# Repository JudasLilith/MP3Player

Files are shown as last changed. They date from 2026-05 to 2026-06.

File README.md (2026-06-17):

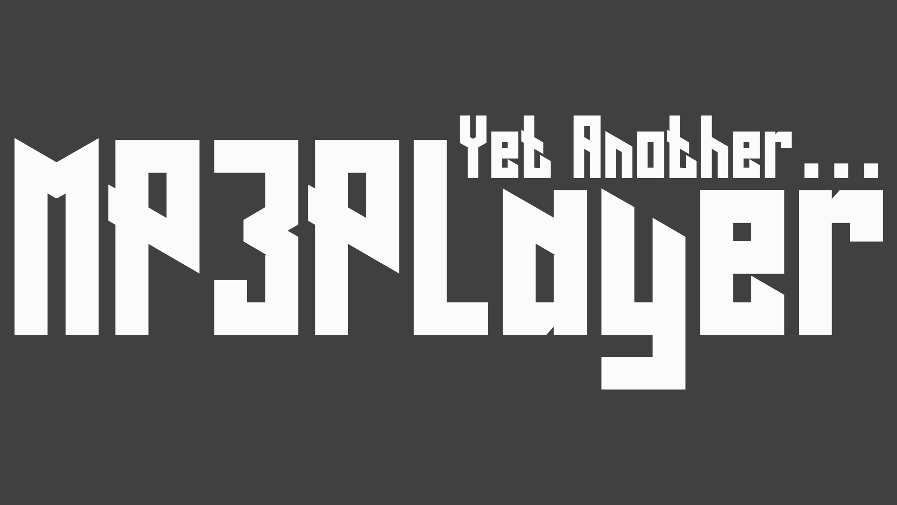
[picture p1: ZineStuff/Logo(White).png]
title


__Yet another MP3 Player, based on the DFRobot player. made for Hack Club Fallout(woohoo!!)__

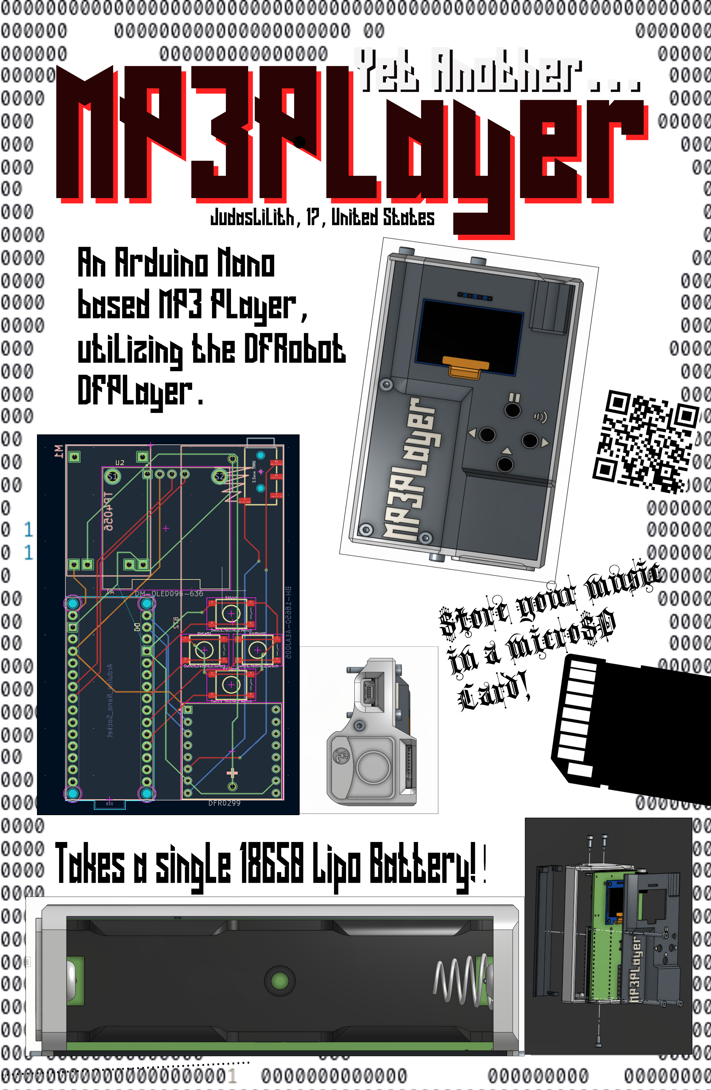
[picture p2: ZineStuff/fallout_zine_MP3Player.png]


## Introduction

Last year, the state of texas passed a law banning phones in all public schools. This came as a devastating effect for people who used their phones for academic purposes and people who listened to music in their free time. This situation made me find ways to listen to my playlist, and prompted me to make this project.

This project is highly influenced from other similar projects, such as:

* <https://github.com/Neutrino-1/Arduino-Soundpod> (this one even has a [instructables page](https://www.instructables.com/Arduino-Retro-Style-MP3-Player/))
* <https://fallout.hackclub.com/projects/755>
* <https://fallout.hackclub.com/projects/2789>

The MP3Player works by using the DFrobot DFPlayer, where all the songs are stored inside a microSD card. Each of the files have a specific 4-digit number, and those are used to find or traverse through the music.

## Gallery

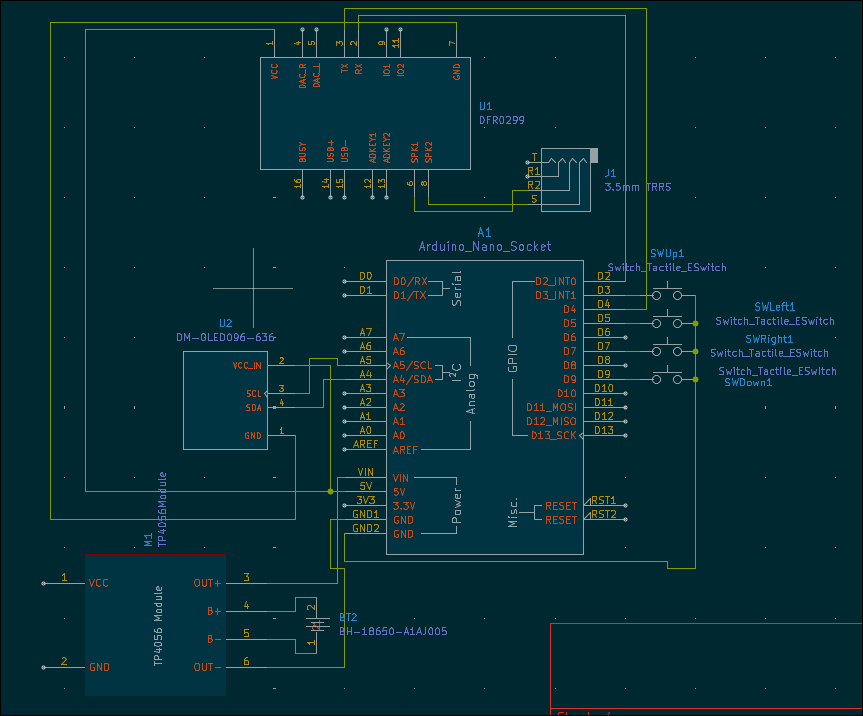
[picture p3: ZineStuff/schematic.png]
schematic

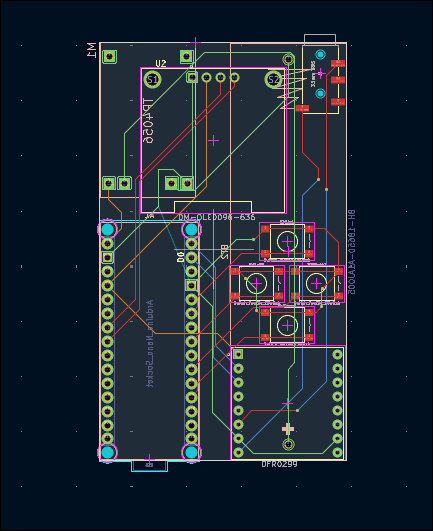
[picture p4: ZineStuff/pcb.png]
pcb

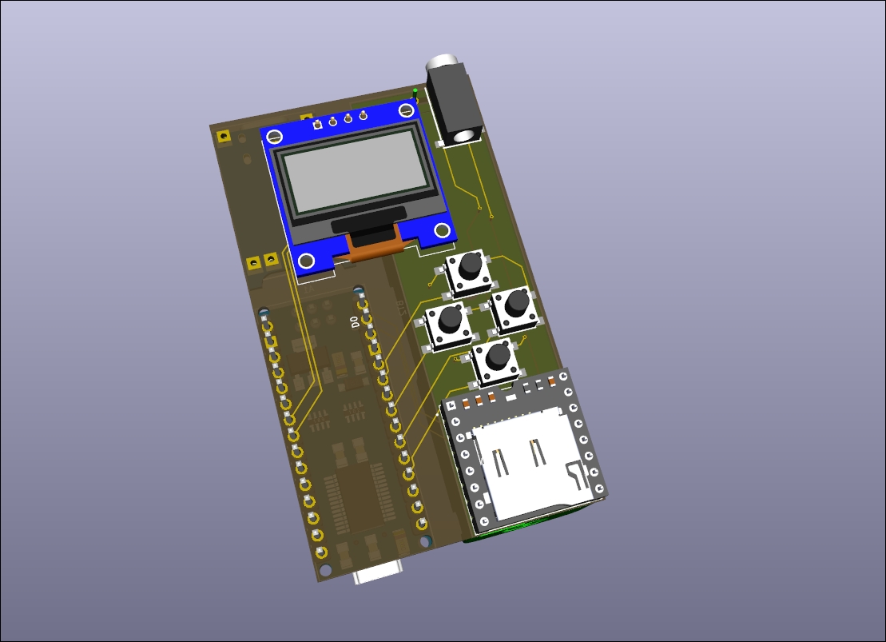
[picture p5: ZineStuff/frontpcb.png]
frontpcb

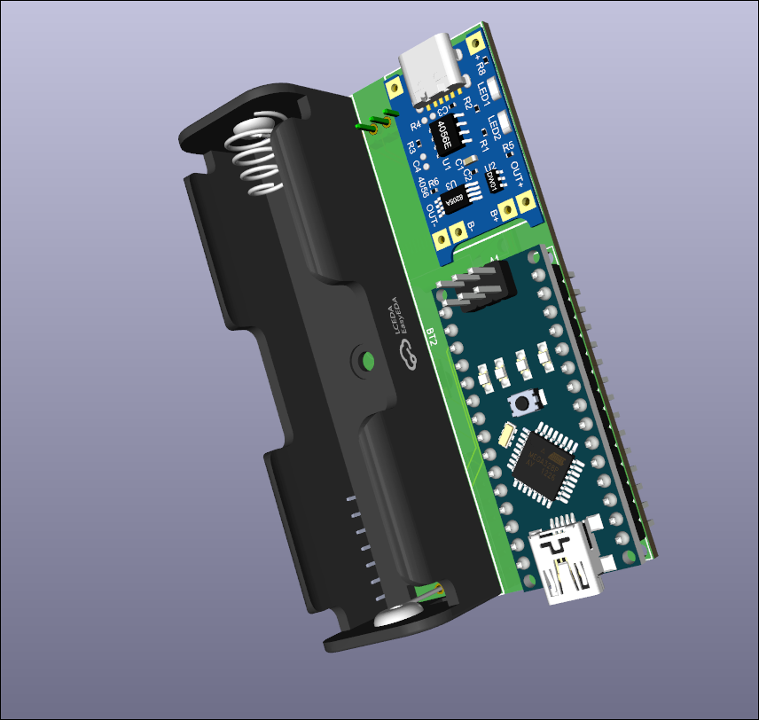
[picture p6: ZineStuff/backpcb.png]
backpcb


### The BOM (Bill of Materials)

| __Name__ | __Link__ | __info__ |
| --- | :----: | :----: |
|DFRobot MP3 Player module | [original seller](https://www.dfrobot.com/product-1121.html) |lwk, clones do not matter just get cheap clones from Aliexpressor or sumn
| SD card | [amazon link](https://www.amazon.com/SanDisk-2-Pack-microSDHC-Memory-2x32GB/dp/B08J4HJ98L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) | any type of SD card will do, this was what I was just used. |
| custom PCB board | [inside the step file](/link) | Will add the files in a minute |
|SSD1036 | [amazon link for bulk](https://www.amazon.com/Hosyond-Display-Self-Luminous-Compatible-Raspberry/dp/B09T6SJBV5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) | Anything is fine, just make sure it's compatible with the Adafruit display library |
|4 Buttons (depending on what kind of keys you want, alter the kicad pcb file) | N/A | I personally just use the common button keys on almost every arduino kits |
|6 M2 nuts | [amazon link](https://www.amazon.com/Fgruh-M2-M3-M4-M5/dp/B0FGX9JGC5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) | Any M2 nuts and bolts will do, just make sure that the nuts are at least 4.5mm on each parallel side.
| 3 M2-5mm Bolts | use above link | For the bottom plate of the casing |
| 3 M2-15mm Bolts | use above link | For connecting the middle casing, along with the top casing. |
| 1 18650 Cell | [amazon link](https://www.amazon.com/Flat-Top-Universal-Flashlights-Headlamps/dp/B0FQB9BGTP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) | they normally sell in bulk, there probably are better ways for you to source these parts.|

### Warning

__Depending on the pack, make sure that you have a method to cut out the leeway remain of the bolts.__

### Custom music

  You can add Custom music to your file, just inside the ./firmware/Music&Script/ for a python file, that would let you import the list yourself and then number them on your own.
  Make sure that the files are in place for the python scripts, and then run the scripts. The script name is "updater.py"

Further information about the [DFRobot Module can be found here.](https://wiki.dfrobot.com/dfr0299/)

## Assembly

* First, make a gerber file with the KiCad files and solder each one in this order:

* The DFPlayer-

* The Battery Holder -

* Arduino Nano-

* The Screen-

* The Buttons

Be sure to print the casing, and have some way to tighten nuts and bolts.

CAD file Link: <https://cad.onshape.com/documents/ecd8843b791ff5437d08f02d/w/4fa01a5ba4f86aa9473803eb/e/f34659960ea4cbceb5ca3625>

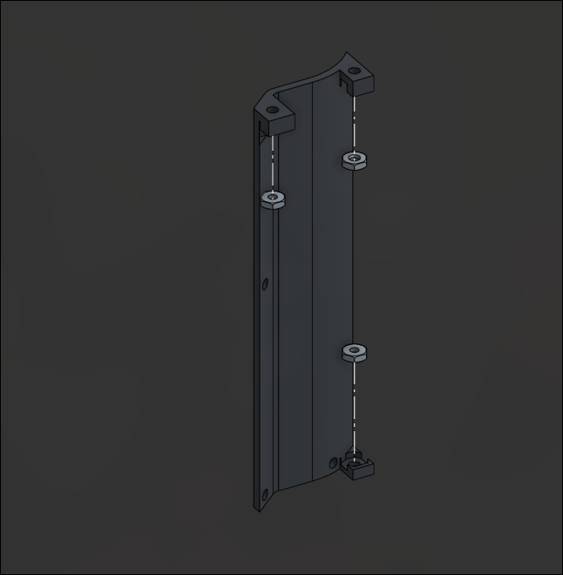
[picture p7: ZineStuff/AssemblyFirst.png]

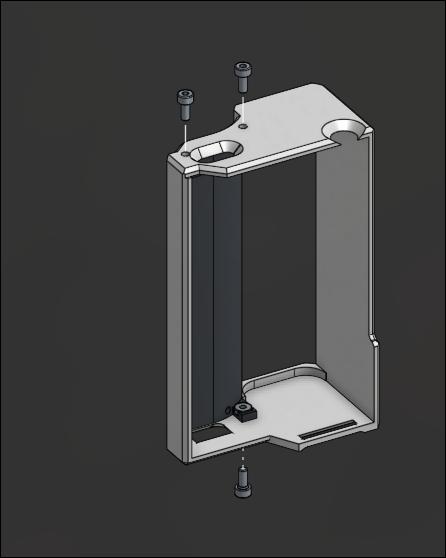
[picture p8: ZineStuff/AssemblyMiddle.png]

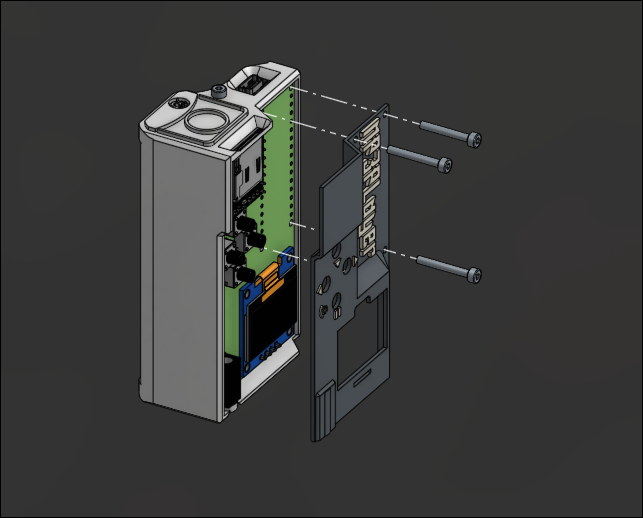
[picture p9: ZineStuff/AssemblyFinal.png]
Assemblyimage


## Using the player

* in flashing the code, do as you will with any microcontroller by connecting to the Arduino IDE, maintain a connection, and press flash.

* Press the up button to toggle stop and play.

* The Right Button passes through each music, and the Left button goes to the previous music

* The Up + Right button to increase volume, the Down + Left button to decrease it.

## Have fun making

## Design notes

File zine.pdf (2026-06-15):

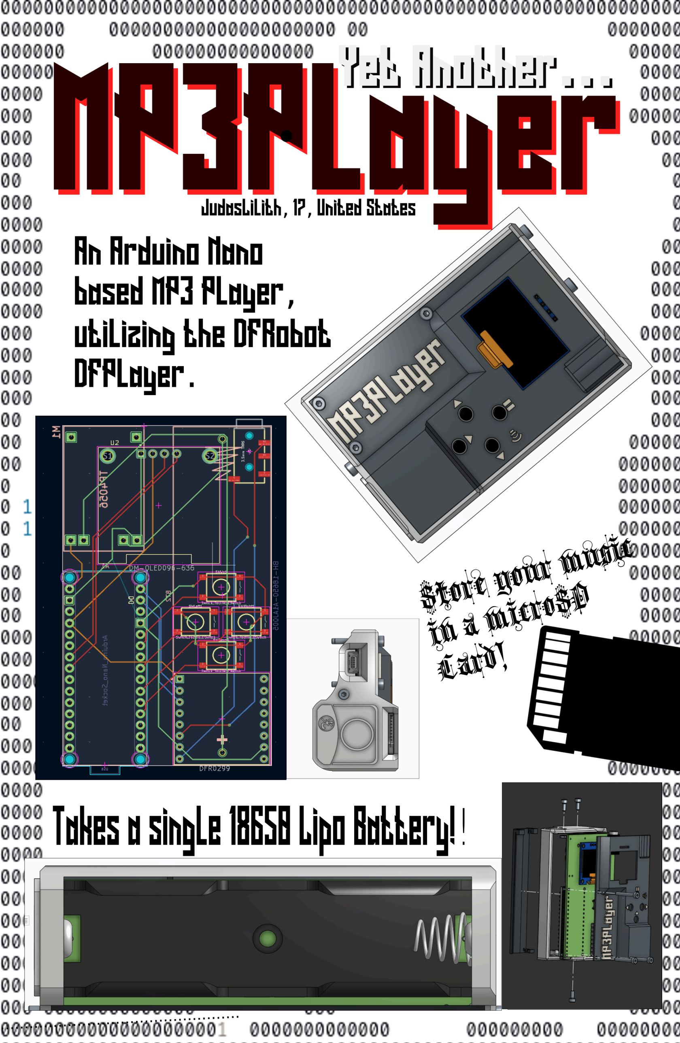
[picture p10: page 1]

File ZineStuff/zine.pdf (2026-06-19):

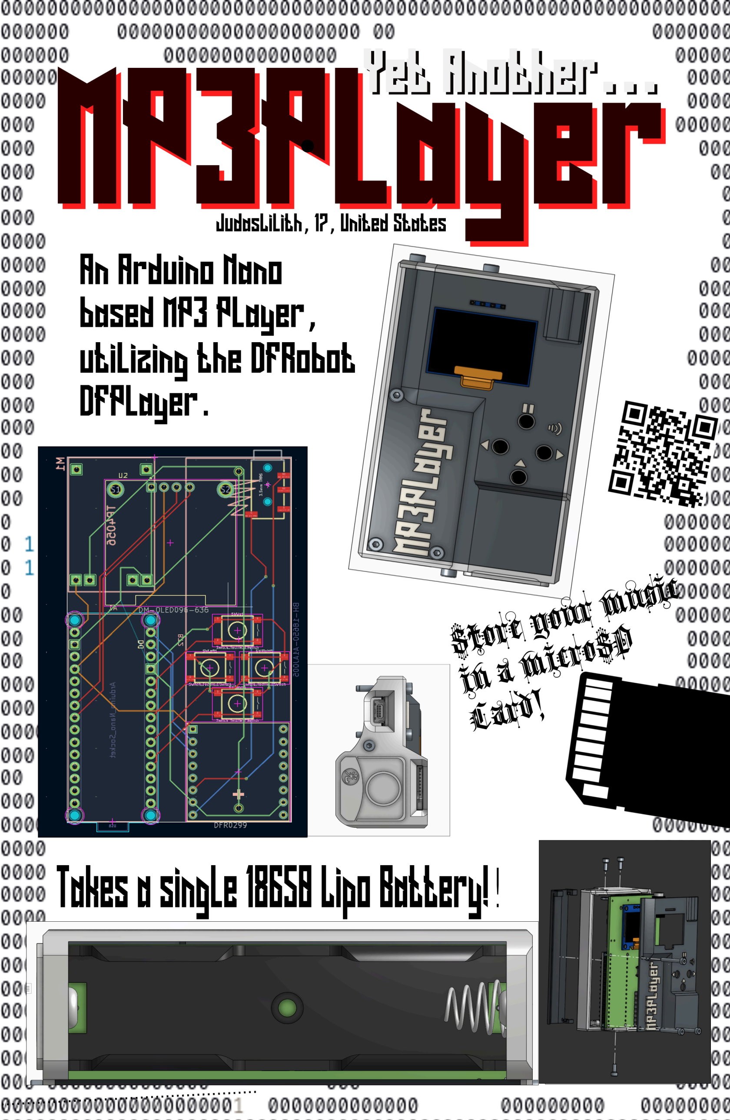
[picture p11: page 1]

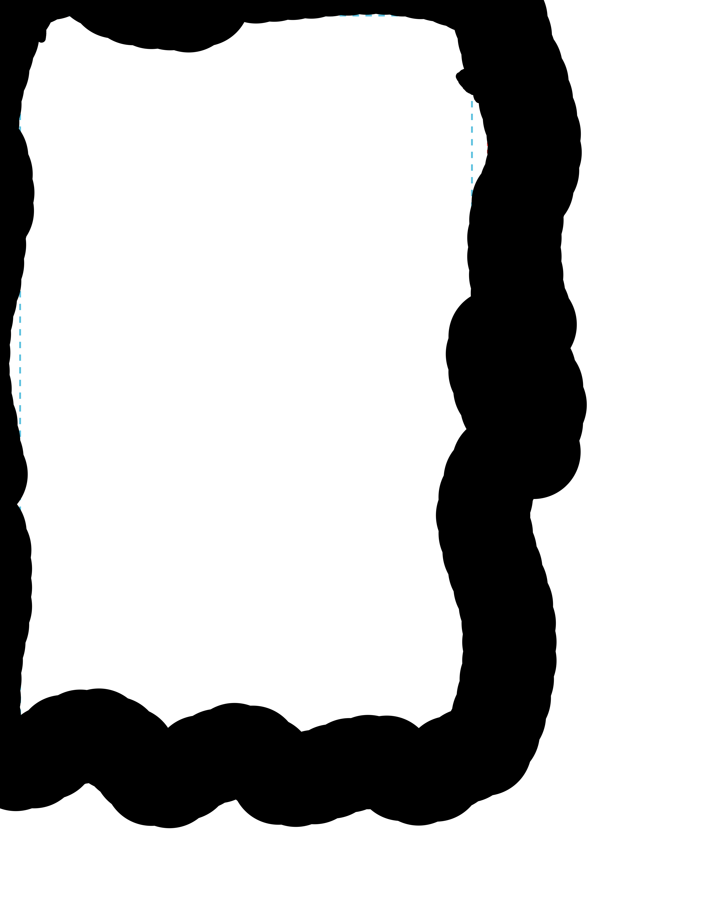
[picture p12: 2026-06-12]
ZineStuff/beforeasciied.png

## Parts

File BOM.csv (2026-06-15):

DFRobot MP3 Player module | https://www.dfrobot.com/product-1121.html | lwk, clones do not matter just get cheap clones from Aliexpressor or sumn
SD card | https://www.amazon.com/SanDisk-2-Pack-microSDHC-Memory-2x32GB/dp/B08J4HJ98L | any type of SD card will do, this was what I was just used.
custom PCB board | inside the step folder | Will add the files in a minute(added now)
SSD1036 | https://www.amazon.com/Hosyond-Display-Self-Luminous-Compatible-Raspberry/dp/B09T6SJBV5 | Anything is fine, just make sure it’s compatible with the Adafruit display library
4 Buttons (depending on what kind of keys you want, alter the kicad pcb file) |  | I personally just use the common button keys on almost every arduino kits
6 M2 nuts | https://www.amazon.com/Fgruh-M2-M3-M4-M5/dp/B0FGX9JGC5 | Any M2 nuts and bolts will do, just make sure that the nuts are at least 4.5mm on each parallel side.
3 M2-5mm Bolts | use above link | For the bottom plate of the casing
3 M2-15mm Bolts | use above link | For connecting the middle casing, along with the top casing.
1 18650 Cell | https://www.amazon.com/Flat-Top-Universal-Flashlights-Headlamps/dp/B0FQB9BGTP | they normally sell in bulk, there probably are better ways for you to source these parts.

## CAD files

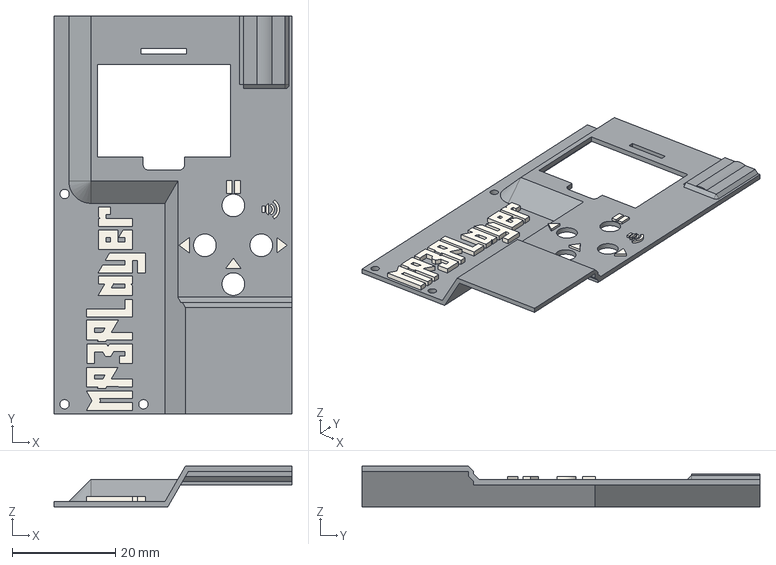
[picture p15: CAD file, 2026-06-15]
hardware/casing/FrontCover.step
46.0 x 76.9 x 7.83 mm

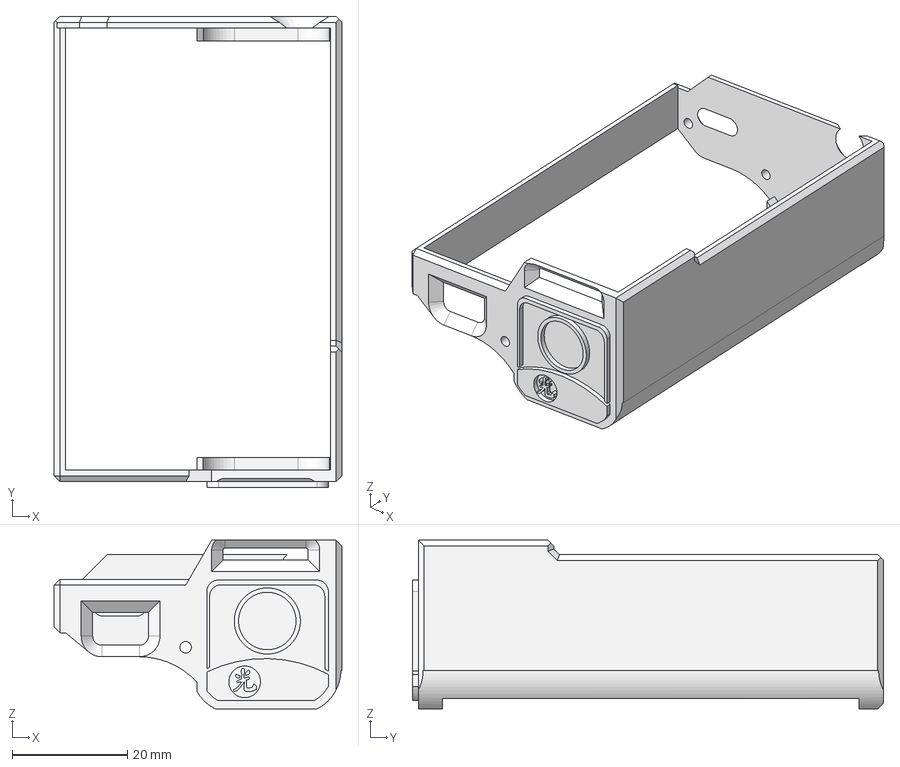
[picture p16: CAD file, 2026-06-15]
hardware/casing/SideCover.step
50.0 x 81.9 x 29.3 mm

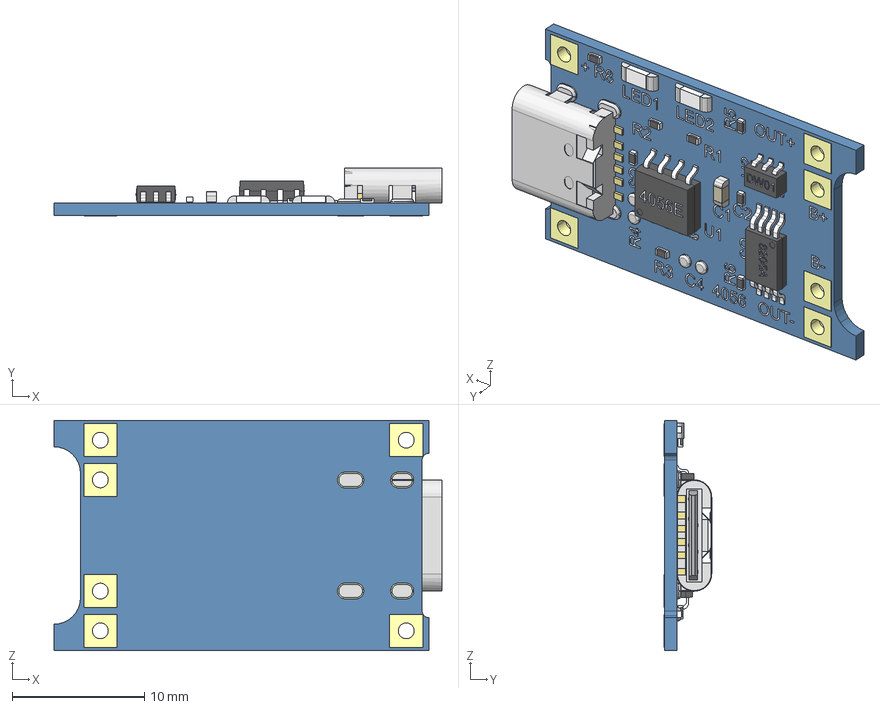
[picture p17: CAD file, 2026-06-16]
hardware/step/HW-373.stp
29.3 x 3.59 x 17.4 mm
pcb Geometry
txt
cu
sold
8205A Geometry
PIN
R Geometry x 6
PIN2 x 6
C Geometry x 2
pin3 x 2
4056E Geometry
Pin4
DW01 Geometry
PIN5
C2 Geometry
pin6
frm
pin7
LED x 2

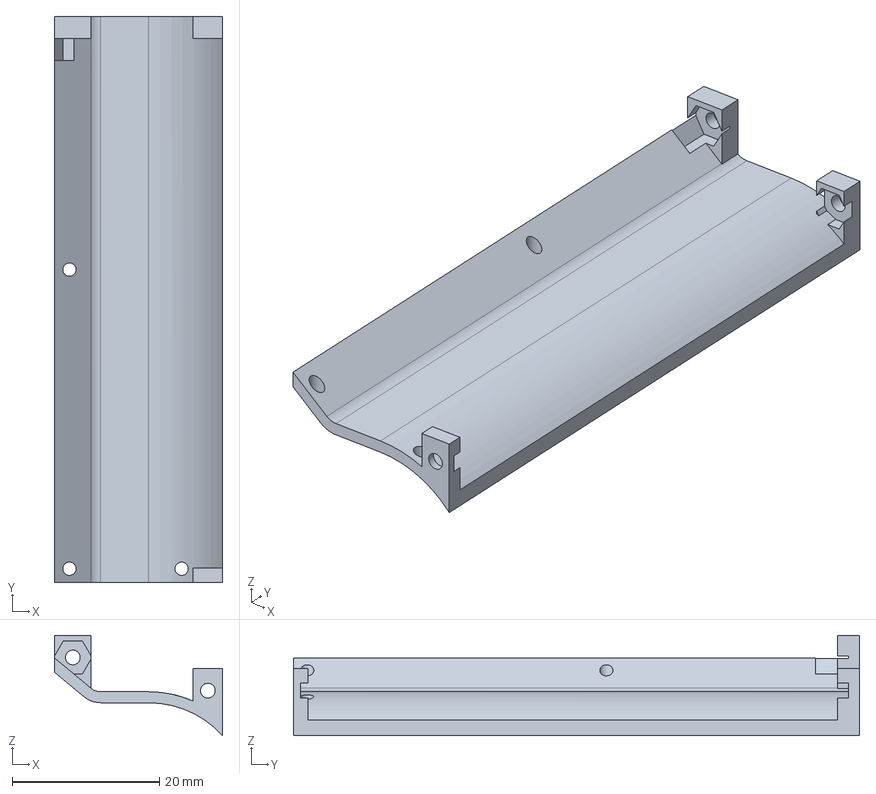
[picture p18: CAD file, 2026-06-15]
hardware/casing/BackCover.step
22.8 x 76.9 x 13.6 mm

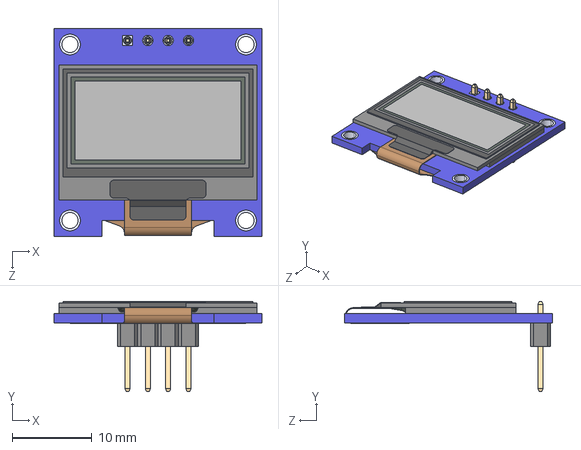
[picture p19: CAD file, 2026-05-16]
hardware/step/DM-OLED096-636.step
26.0 x 11.3 x 26.0 mm
DM-OLED096-636_Module
DM-OLED096-636_Panel

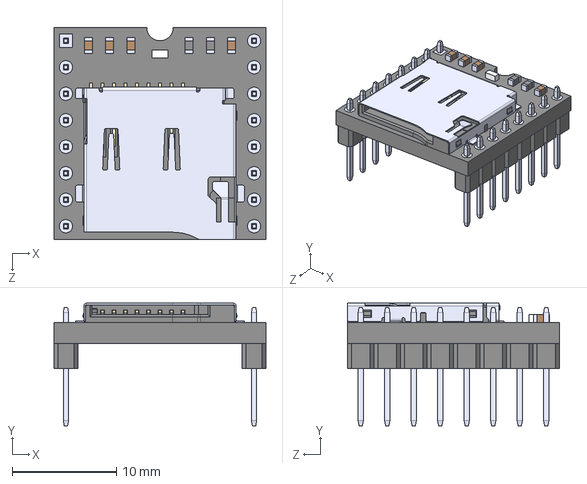
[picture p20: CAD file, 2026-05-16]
hardware/step/DFR0299.step
20.3 x 11.8 x 20.3 mm

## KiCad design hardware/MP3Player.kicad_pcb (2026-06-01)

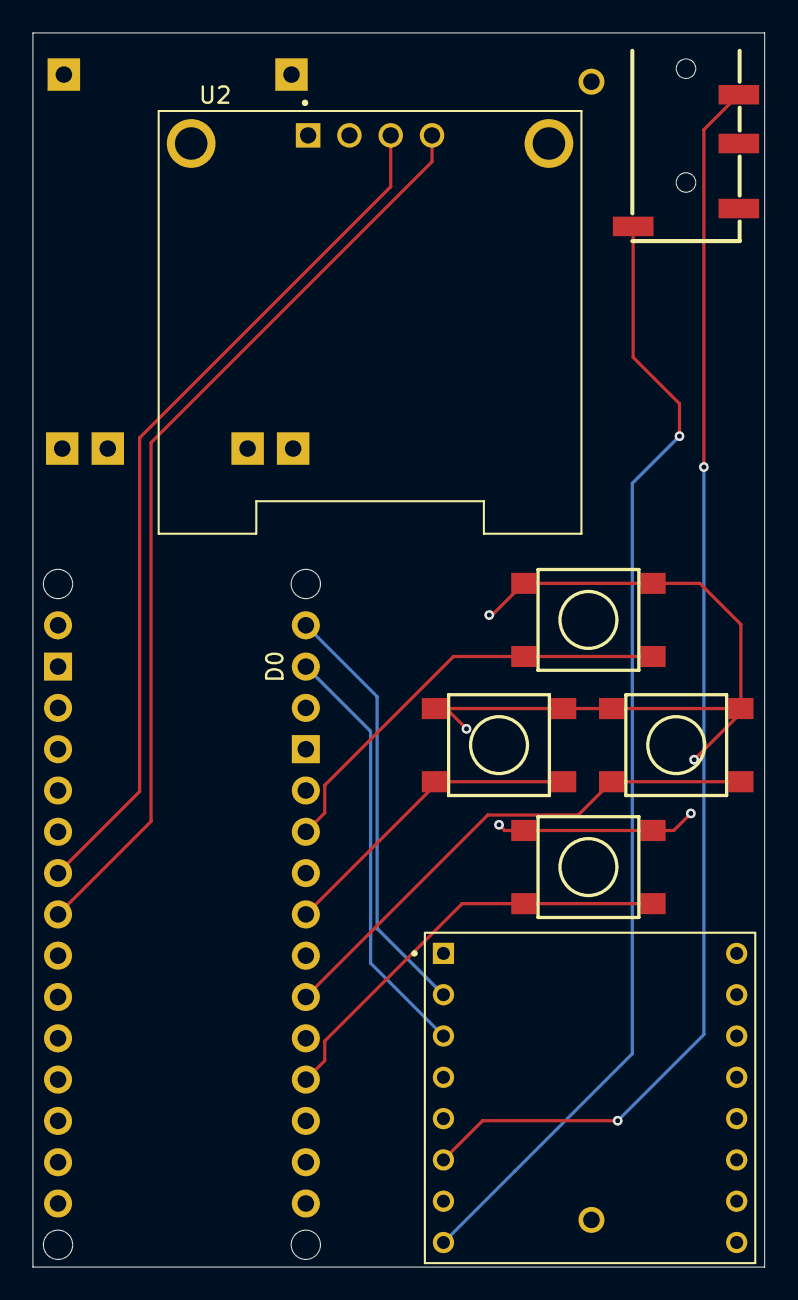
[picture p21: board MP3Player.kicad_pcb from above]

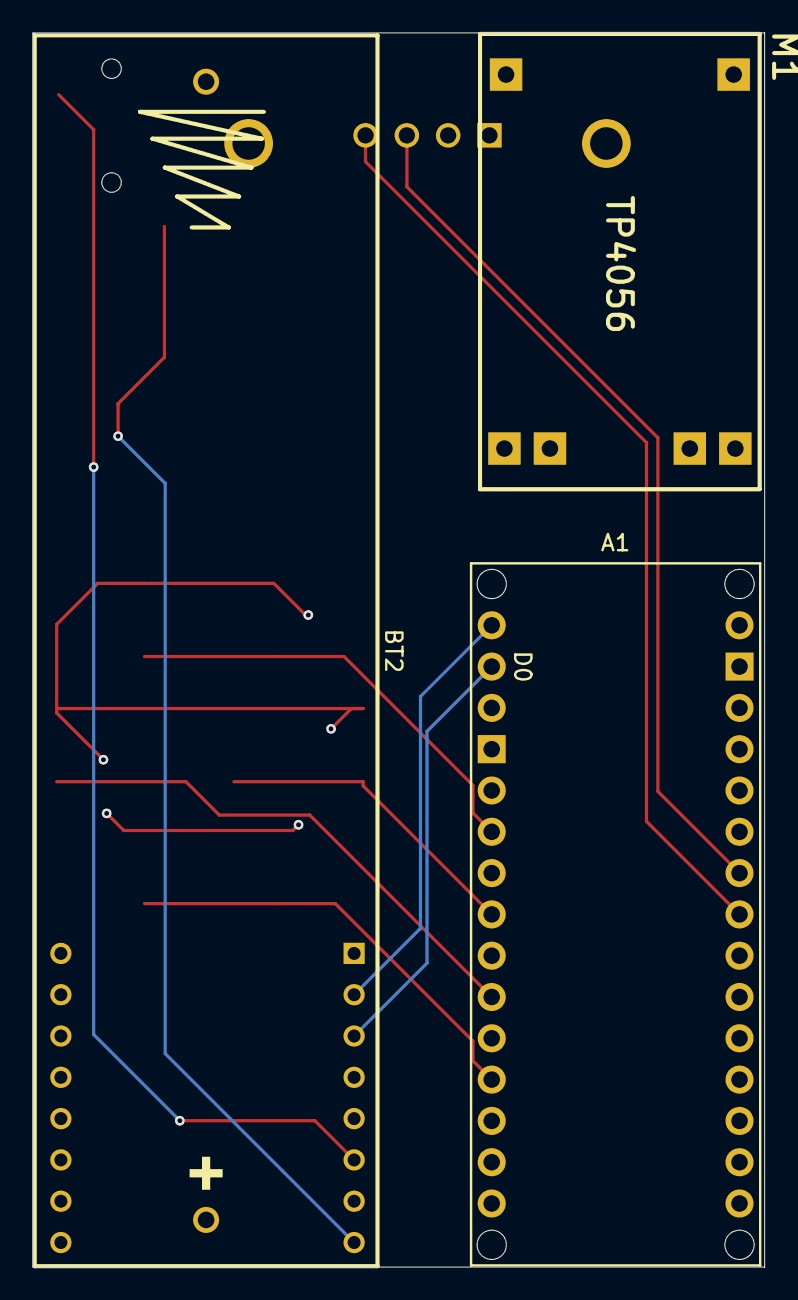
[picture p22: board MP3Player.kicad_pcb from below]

Board: 4 copper layers, 45.0 x 75.9 mm, 10 parts (3 on the bottom side), 15 nets.

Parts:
A1: Arduino_Nano_Socket
BT2: BH-18650-A1AJ005
J1: 3.5mm TRRS; Audio_Jack_3.5mm_TRRS_SMD_RA
M1: TP4056Module
SWDown1: Switch_Tactile_ESwitch; Push_SMD_6.2x6.2mm
SWLeft1: Switch_Tactile_ESwitch; Push_SMD_6.2x6.2mm
SWRight1: Switch_Tactile_ESwitch; Push_SMD_6.2x6.2mm
SWUp1: Switch_Tactile_ESwitch; Push_SMD_6.2x6.2mm
U1: DFR0299; MODULE_DFR0299
U2: DM-OLED096-636; MODULE_DM-OLED096-636

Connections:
GND: U1.7 (GND), U1.10 (GND), U2.1 (GND)
unnamed: A1.A4 (A4/SDA), U2.4 (SDA)
unnamed: A1.A5 (A5/SCL), U2.3 (SCL)
unnamed: A1.D0 (D0/RX), U1.3 (TX)
unnamed: A1.D1 (D1/TX), U1.2 (RX)
unnamed: A1.D3 (D3_INT1), SWUp1.2
unnamed: A1.D5, SWLeft1.2
unnamed: A1.D7, SWRight1.2
unnamed: A1.D9, SWDown1.2
unnamed: BT2.2, M1.4 (B+)
unnamed: BT2.1, M1.5 (B-)
unnamed: A1.VIN, M1.3 (OUT+)
unnamed: J1.R2, U1.6 (SPK1)
unnamed: J1.S, U1.8 (SPK2)
unnamed: A1.5V, U1.1 (VCC), U2.2 (VCC_IN)

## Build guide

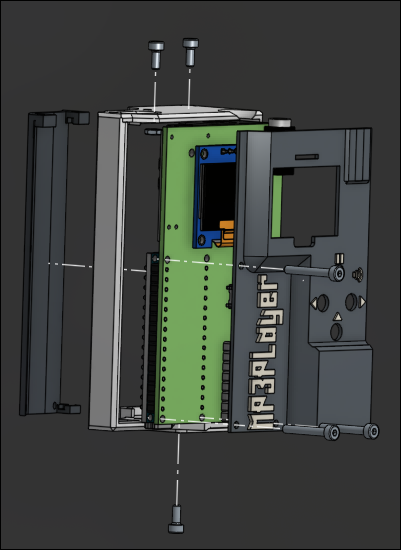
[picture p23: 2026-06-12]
ZineStuff/AssemblyAll.png

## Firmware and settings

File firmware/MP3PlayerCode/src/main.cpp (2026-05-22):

#include <Arduino.h>

#include <SPI.h>
#include <Wire.h>
#include <Adafruit_SSD1306.h>
#include "FreeMonoBold9pt7b.h"
#include "FreeMonoBold9pt7b.h"
#include "FreeSansBoldOblique18pt7b.h"



//defines the buttons
boolean LeftButton;
boolean RightButton;
boolean UpButton;
boolean DownButton;

// God I fucking hate C++
String str(boolean thing) {
  if (thing)
    return "true";
  return "false";
}

static const unsigned char PROGMEM image_battery_17_bits[] = {0x00,0x00,0x00,0x0f,0xff,0xfe,0x10,0x00,0x01,0x10,0x00,0x0d,0x70,0x00,0x0d,0x80,0x00,0x0d,0x80,0x00,0x0d,0x80,0x00,0x0d,0x80,0x00,0x0d,0x80,0x00,0x0d,0x70,0x00,0x0d,0x10,0x00,0x0d,0x10,0x00,0x01,0x0f,0xff,0xfe,0x00,0x00,0x00,0x00,0x00,0x00};
static const unsigned char PROGMEM image_Layer_6_bits[] = {0x80};





#define SCREEN_ADDRESS 0x3C
Adafruit_SSD1306 display = Adafruit_SSD1306(128, 64, &Wire);




void TitleScreen(){
  
  display.clearDisplay();

  display.setTextColor(1);
  display.setTextWrap(false);
  display.setFont(&FreeSansBoldOblique18pt7b);
  display.setCursor(7, 54);
  display.print("Player");

  display.setCursor(24, 27);
  display.print("MP3");

  display.display();

}

void MainScreen(){

  display.clearDisplay(); // maybe being unable to clear is the reaosn....

  display.setTextColor(1);
  display.setTextWrap(false);
  display.setCursor(3, 14);
  display.print("Now Playing:");

  display.setFont(&FreeMonoBold9pt7b);
  display.setCursor(2, 35);
  display.print("SONG111");

  display.setFont();
  display.setCursor(2, 40);
  display.print("Next Song:");

  display.setFont(&FreeMonoBold9pt7b);
  display.setCursor(3, 61);
  display.print("SONG111");

  display.drawBitmap(101, 3, image_battery_17_bits, 24, 16, 1);
  display.drawBitmap(35, 5, image_Layer_6_bits, 1, 1, 1);

  display.display();

}






void setup() {  // put your setup code here, to run once:

  display.begin(SSD1306_SWITCHCAPVCC, SCREEN_ADDRESS);

  Serial.begin(115200);

  display.setTextSize(1);      
  display.setTextColor(SSD1306_WHITE);
  display.setCursor(0, 0);     
  display.display();
  delay(1000);

  //TitleScreen();
  MainScreen();

  delay(100);

  pinMode(9, INPUT);
  pinMode(7, INPUT);
  pinMode(5, INPUT);
  pinMode(3, INPUT);

  digitalWrite(9, HIGH);
  digitalWrite(7, HIGH);
  digitalWrite(5, HIGH);
  digitalWrite(3, HIGH);

  delay(400);
  Serial.println("this should work somehow"); //so this somehow worked, now we do know it gets to this point


}













void loop() {
  // put your main code here, to run repeatedly:
  UpButton = digitalRead(9);
  LeftButton = digitalRead(7);
  DownButton = digitalRead(5);
  RightButton = digitalRead(3);
  Serial.println(str(UpButton)+" "+str(DownButton)+" " + str(LeftButton)+" " + str(RightButton));
  if (!(UpButton)){
    //MainScreen(12);
    while ( !(DownButton) ){
      delay(300);
      Serial.println("yay it worked");
    }
  }
  delay(200);
}

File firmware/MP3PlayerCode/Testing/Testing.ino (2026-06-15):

#include <Adafruit_SSD1306.h>
#include "DFRobotDFPlayerMini.h"
#include "ScreenFunction.h"

//defines the buttons
boolean LeftButton;
boolean RightButton;
boolean UpButton;
boolean DownButton;

int index = 0;
boolean toggle = true;
boolean newToggle=false;

int buffer = 50; // buffer in case the two button presses have to register

#define SCREEN_ADDRESS 0x3C
Adafruit_SSD1306 display = Adafruit_SSD1306(128, 64, &Wire);

DFRobotDFPlayerMini myDFPlayer; //declare the DFPlayer itself



#include <SoftwareSerial.h>
SoftwareSerial softSerial(/*rx =*/4, /*tx =*/5);
#define FPSerial softSerial


void TitleScreen(Adafruit_SSD1306 display){
  
  display.clearDisplay();

  display.setTextColor(1);
  display.setTextWrap(false);

  display.setCursor(7, 54);
  display.print("Player");

  display.setCursor(24, 27);
  display.print("MP3");

  display.display();

}

void MainScreen(Adafruit_SSD1306 display){

  display.clearDisplay();

  display.setTextColor(1);
  display.setTextWrap(false);
  display.setCursor(3, 14);
  display.print("Now Playing:");

  display.setCursor(2, 35);
  display.print("SONG111");




  display.display();

}


void UpdateScreen(Adafruit_SSD1306 display, int index, boolean UpButton,boolean DownButton,boolean LeftButton, boolean RightButton) {
  display.clearDisplay();
  if (RightButton && DownButton){ //Plays a track, 
    myDFPlayer.next();
    index++;
    delay(buffer);

  }

  if (RightButton && DownButton){ //Pressing  right and left = Volume goes up
    myDFPlayer.volumeUp();
    delay(buffer);
  }

  if (LeftButton && !(UpButton)){
    myDFPlayer.previous();
    delay(buffer);
  }

  if (RightButton && UpButton){
    myDFPlayer.volumeDown();
    delay(buffer);
  }
    // toggling
  if (UpButton){
    if (toggle =! newToggle){
      myDFPlayer.stop(); 
      newToggle = toggle;     
    }

    else{
      myDFPlayer.play();
      newToggle = false;
    }
  }


  display.setTextColor(1);
  display.setTextWrap(false);
  display.setCursor(3, 14);

  display.print("Now Playing:");
  display.print(index);
  display.println( "/30");
}






void setup() { 
  if (myDFPlayer.available()) {
    printDetail(myDFPlayer.readType(), myDFPlayer.read()); //Print the detail message from DFPlayer to handle different errors and states.
  }

  display.begin(SSD1306_SWITCHCAPVCC, SCREEN_ADDRESS);

  Serial.begin(115200);

  display.setTextSize(1);      
  display.setTextColor(SSD1306_WHITE);
  display.setCursor(0, 0);     
  display.display();
  
  
  delay(1000);

  TitleScreen(display);
  
  delay(1000);
  
  MainScreen(display);

  delay(1000);

  pinMode(9, INPUT);
  pinMode(7, INPUT);
  pinMode(5, INPUT);
  pinMode(3, INPUT);

  digitalWrite(9, HIGH);
  digitalWrite(7, HIGH);
  digitalWrite(5, HIGH);
  digitalWrite(3, HIGH);


  delay(400);
  int index = 0;
  Serial.println(F("this should work somehow")); 
  toggle = false;
  myDFPlayer.EQ(DFPLAYER_EQ_NORMAL);
}




void loop() {

  UpButton = (digitalRead(9) == HIGH);
  LeftButton = (digitalRead(7) == HIGH);
  DownButton = (digitalRead(5) == HIGH);
  RightButton = (digitalRead(3) == HIGH);

  if (!(UpButton)){
    Serial.println(F("Up Button"));
  }
  if (!(DownButton)){

    Serial.println(F("Down"));
  }
  if (!(LeftButton)){
    Serial.println(F("Left"));

  }
  if (!(RightButton)){
    Serial.println(F("Right"));
    
  }


  
    

  //Serial.println(!(UpButton) + !(DownButton) + !(LeftButton) + !(RightButton));
  //UpdateScreen(display, index, !(UpButton), !(DownButton), !(LeftButton), !(RightButton));

}






























void printDetail(uint8_t type, int value){
  switch (type) {
    case TimeOut:
      Serial.println(F("Time Out!"));
      break;
    case WrongStack:
      Serial.println(F("Stack Wrong!"));
      break;
    case DFPlayerCardInserted:
      Serial.println(F("Card Inserted!"));
      break;
    case DFPlayerCardRemoved:
      Serial.println(F("Card Removed!"));
      break;
    case DFPlayerCardOnline:
      Serial.println(F("Card Online!"));
      break;
    case DFPlayerUSBInserted:
      Serial.println("USB Inserted!");
      break;
    case DFPlayerUSBRemoved:
      Serial.println("USB Removed!");
      break;
    case DFPlayerPlayFinished:
      Serial.print(F("Number:"));
      Serial.print(value);
      Serial.println(F(" Play Finished!"));
      break;
    case DFPlayerError:
      Serial.print(F("DFPlayerError:"));
      switch (value) {
        case Busy:
          Serial.println(F("Card not found"));
          break;
        case Sleeping:
          Serial.println(F("Sleeping"));
          break;
        case SerialWrongStack:
          Serial.println(F("Get Wrong Stack"));
          break;
        case CheckSumNotMatch:
          Serial.println(F("Check Sum Not Match"));
          break;
        case FileIndexOut:
          Serial.println(F("File Index Out of Bound"));
          break;
        case FileMismatch:
          Serial.println(F("Cannot Find File"));
          break;
        case Advertise:
          Serial.println(F("In Advertise"));
          break;
        default:
          break;
      }
      break;
    default:
      break;
  }
  
}

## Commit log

2026-05-16 added platformio
    [.step, DFR0299.step, DM-OLED096-636.step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]
2026-05-21 Just finished the buttons working, time to grind on lopaka
2026-06-01 general update
    [MP3Player.kicad_pcb, MP3Player.kicad_sch]
2026-06-15 upload step files
    [BackCover.step, FrontCover.step, SideCover.step]
2026-06-15 final push
    [BOM.csv, BOM.ods]
2026-06-16 reorganizing v2
    [.step, BOM.ods]
